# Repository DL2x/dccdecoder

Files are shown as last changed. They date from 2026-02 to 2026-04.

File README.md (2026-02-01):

This is my try at building my own dcc decoder. The code is funktional with a small PC817 Opto just hooked up to the track and an arduino, but Ive tried making a pcb for it (order is ongoing as of writing this).

There is currently no code for the PCB, as I dont yet have one of them here and cant test on it.

The PCB has support for 3 individual inputs (e.g. left rail, right rail and ac contact or overhead wire), with all of them providing power.

It does not support anything other than standard dcc, this includes no support for any analog system.

There are jumpers for connecting an AC motor: desolder both of then, then hook the 2 wires of the coil to the left and right ports and the neutral wire to the middle one. For DC motors just use the outer ones.

Feel free to contribute to this project!

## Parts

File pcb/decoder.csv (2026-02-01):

ID | Bezeichner | Footprint | Stückzahl | Bezeichnung | Anbieter und Referenz
1 | Q6,Q5,Q8,Q15,Q12,Q10 | SOT-23 | 6 | BC547
2 | R19,R8,R7,R16,R24,R14,R5,R28 | C_0201_0603Metric | 8 | 100
3 | D3,D5,D4,D15,D1,D2,D6 | D_SMA | 7 | SS34
4 | R27,R25,R15,R2,R21,R23,R29,R6,R18,R17,R4,R11 | C_0201_0603Metric | 12 | 100k
5 | R3 | C_0201_0603Metric | 1 | 10k
6 | R9,R20,R10,R13,R22,R26,R12,R30 | C_0201_0603Metric | 8 | 2k
7 | D9,D14,D10,D11,D12,D13 | D_SOD-523 | 6 | 15V
8 | C2,C4,C5 | C_0201_0603Metric | 3 | 100nF
9 | Q3,Q13,Q7,Q2,Q11,Q9 | TO-252-3_TabPin2 | 6 | FQP27P06
10 | JP3,JP2 | SolderJumper-2_P1.3mm_Bridged_Pad1.0x1.5mm | 2 | Jumper_2_Bridged
11 | Q1,Q4 | SOT-23 | 2 | IRLZ44N
12 | U1 | SOT-223-3_TabPin2 | 1 | LM7805_TO220
13 | U3 | SOIC-8_3.9x4.9mm_P1.27mm | 1 | 6N137
14 | R1 | C_0201_0603Metric | 1 | 1,3k
15 | JP1 | SolderJumper-2_P1.3mm_Open_Pad1.0x1.5mm | 1 | Jumper_2_Open
16 | D8 | D_SMA | 1 | D_TVS

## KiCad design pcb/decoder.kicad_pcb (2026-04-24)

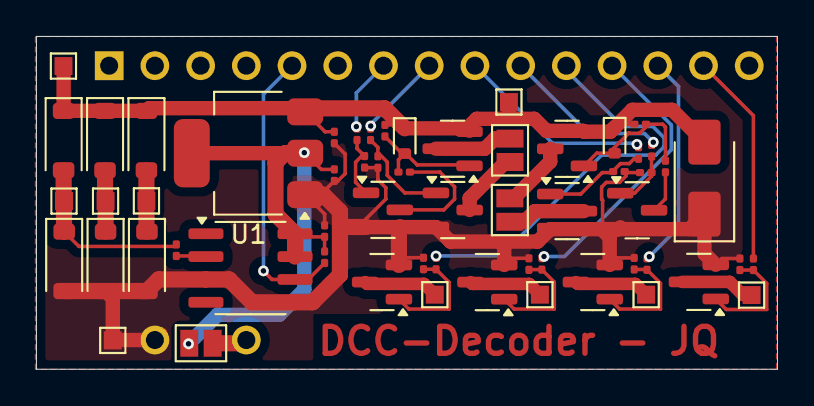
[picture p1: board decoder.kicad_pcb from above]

Board: 2 copper layers, 41.2 x 18.5 mm, 60 parts (1 on the bottom side), 37 nets.

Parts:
A1: Arduino_Nano_v3.x; Arduino_Nano
C2, C4, C5: 100nF; C_0201_0603Metric
D1, D2, D3, D4, D5, D15: MBR120VLSFT1G; D_SOD-123
D8: SMAJ24CA; D_SMA
D11, D12: BZT585B15T-7; D_SOD-523
J1, J2, J3, J4, J5, J6, J7, J9, J11, J12: Conn_01x01_Socket; TestPoint_Pad_1.0x1.0mm
JP1, JP2, JP4: Jumper_2_Open; SolderJumper-2_P1.3mm_Open_Pad1.0x1.5mm
Q1, Q4, Q7, Q8, Q10, Q14: FDN5630; SOT-23
Q2, Q3: NTR4171P; SOT-23
Q5, Q6: BC817; SOT-23
R1: 1,3k; C_0201_0603Metric
R2, R4, R6, R11, R15, R17, R23, R31: 100k; C_0201_0603Metric
R3: 10k; C_0201_0603Metric
R5, R7, R8, R14, R16, R18, R24, R32: 100; C_0201_0603Metric
R9, R10, R12, R13: 2k; C_0201_0603Metric
U1: AMS1117; SOT-223-3_TabPin2
U3: 6N137; SOIC-8_3.9x4.9mm_P1.27mm

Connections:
/5V: C2.1, C4.2, JP1.2 (B), R3.1, U1.2 (VO), U3.7 (EN), U3.8 (VCC)
/GND: A1.29 (GND), C2.2, C4.1, C5.1, D3.2 (A), D4.2 (A), D5.2 (A), D8.1 (A1), J11.1, Q1.2 (S), Q4.2 (S), Q5.2 (E), Q6.2 (E), Q7.2 (S), Q8.2 (S), Q10.2 (S), Q14.2 (S), R2.1, R6.1, R10.2, R13.2, R15.1, R17.1, R23.1, R31.1, U1.1 (ADJ), U3.3 (C), U3.5 (GND)
/Motor_A: JP4.1 (A), Q1.3 (D)
/Motor_A1: JP4.2 (B), Q2.3 (D)
/Motor_B: JP2.2 (B), Q4.3 (D)
/Motor_B1: JP2.1 (A), Q3.3 (D)
/VM: C5.2, D1.1 (K), D2.1 (K), D8.2 (A2), D11.1 (K), D12.1 (K), D15.1 (K), J9.1, J12.1, Q2.2 (S), Q3.2 (S), R4.1, R11.2, U1.3 (VI)
unnamed: A1.27 (+5V), JP1.1 (A)
unnamed: A1.5 (D2), R3.2, U3.6 (VO)
unnamed: A1.7 (D4), R12.1
unnamed: A1.8 (D5), R14.2
unnamed: A1.9 (D6), R5.2
unnamed: A1.10 (D7), R9.1
unnamed: A1.11 (D8), R32.2
unnamed: A1.12 (D9), R24.2
unnamed: A1.13 (D10), R18.2
unnamed: A1.14 (D11), R16.2
unnamed: D1.2 (A), D4.1 (K), J5.1
unnamed: D2.2 (A), D5.1 (K), J4.1
unnamed: D11.2 (A), Q3.1 (G), R4.2, R8.2
unnamed: D12.2 (A), Q2.1 (G), R7.2, R11.1
unnamed: D3.1 (K), D15.2 (A), J6.1, R1.2
unnamed: J1.1, Q8.3 (D)
unnamed: J2.1, Q7.3 (D)
unnamed: J3.1, Q10.3 (D)
unnamed: J7.1, Q14.3 (D)
unnamed: Q1.1 (G), R2.2, R5.1
unnamed: Q4.1 (G), R6.2, R14.1
unnamed: Q5.1 (B), R9.2, R13.1
unnamed: Q5.3 (C), R7.1
unnamed: Q6.1 (B), R10.1, R12.2
unnamed: Q6.3 (C), R8.1
unnamed: Q7.1 (G), R15.2, R16.1
unnamed: Q8.1 (G), R17.2, R18.1
unnamed: Q10.1 (G), R23.2, R24.1
unnamed: Q14.1 (G), R31.2, R32.1
unnamed: R1.1, U3.2 (A)

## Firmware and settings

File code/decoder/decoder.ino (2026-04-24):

#include <Arduino.h>

const byte dccPin = 2;

// ============================================================
// Ziel-Datentyp
// ============================================================

struct lokdada {
  bool richtung;         // true = vorwärts
  int geschwindigkeit;   // 0..127 normiert
  int funktionen[29];    // F0..F28, jeweils 0 oder 1
};

lokdada lokData;

// optional: zum Erkennen von Änderungen
lokdada prevLokData;

// Adressfilter
volatile int TARGET_ADDR = -1;   // -1 = alle, sonst kurze/lange Adresse

// nur für Diagnose
int currentDecodedAddr = -1;
bool currentDecodedIsLong = false;

// ============================================================
// DCC Rohdecoder (funktionierende Basis)
// ============================================================

volatile unsigned long lastEdge = 0;
volatile int pendingHalf = -1;      // -1 = none, 0 = long, 1 = short

volatile byte packet[8];
volatile byte packetLen = 0;
volatile byte curByte = 0;
volatile byte bitCount = 0;
volatile byte preambleCount = 0;
volatile bool inPacket = false;
volatile bool packetReady = false;

void resetDecoder() {
  pendingHalf = -1;
  packetLen = 0;
  curByte = 0;
  bitCount = 0;
  preambleCount = 0;
  inPacket = false;
}

void finishPacket() {
  packetReady = true;
  inPacket = false;
  curByte = 0;
  bitCount = 0;
  preambleCount = 1; // End-1 kann schon Teil der nächsten Präambel sein
}

void pushBit(byte b) {
  if (!inPacket) {
    if (b == 1) {
      preambleCount++;
    } else {
      if (preambleCount >= 10) {
        inPacket = true;
        packetLen = 0;
        curByte = 0;
        bitCount = 0;
      }
      preambleCount = 0;
    }
    return;
  }

  if (bitCount < 8) {
    curByte = (curByte << 1) | b;
    bitCount++;
    return;
  }

  // 9. Bit = Separator / Endbit
  if (packetLen < sizeof(packet)) {
    packet[packetLen++] = curByte;
  } else {
    resetDecoder();
    return;
  }

  curByte = 0;
  bitCount = 0;

  if (b == 1) {
    finishPacket();
  }
}

void dccISR() {
  unsigned long now = micros();
  unsigned long dt = now - lastEdge;
  lastEdge = now;

  int halfType = -1;

  // An deine Messung angepasst
  if (dt >= 44 && dt <= 68) {
    halfType = 1;   // kurze Halbwelle = DCC "1"
  } else if (dt >= 90 && dt <= 700) {
    halfType = 0;   // lange Halbwelle = DCC "0"
  } else {
    pendingHalf = -1;
    return;
  }

  if (pendingHalf == -1) {
    pendingHalf = halfType;
    return;
  }

  if (pendingHalf == halfType) {
    pushBit((byte)halfType);
  }

  pendingHalf = -1;
}

// ============================================================
// Hilfsfunktionen
// ============================================================

void resetLokData(lokdada &d) {
  d.richtung = true;
  d.geschwindigkeit = 0;
  for (int i = 0; i < 29; i++) d.funktionen[i] = 0;
}

void copyLokData(const lokdada &src, lokdada &dst) {
  dst.richtung = src.richtung;
  dst.geschwindigkeit = src.geschwindigkeit;
  for (int i = 0; i < 29; i++) dst.funktionen[i] = src.funktionen[i];
}

bool lokDataEquals(const lokdada &a, const lokdada &b) {
  if (a.richtung != b.richtung) return false;
  if (a.geschwindigkeit != b.geschwindigkeit) return false;
  for (int i = 0; i < 29; i++) {
    if (a.funktionen[i] != b.funktionen[i]) return false;
  }
  return true;
}

// Normierung auf 0..127
int normalizeSpeed(int rawStep, int rawMax) {
  if (rawStep <= 0) return 0;
  if (rawMax <= 0) return 0;

  long num = (long)(rawStep - 1) * 126L;
  long den = (long)(rawMax - 1);
  long scaled = 1L + (num + den / 2) / den;   // gerundet

  if (scaled < 1) scaled = 1;
  if (scaled > 127) scaled = 127;

  return (int)scaled;
}

bool packetXorOk(const byte* local, byte len) {
  if (len < 3) return false;
  byte x = 0;
  for (byte i = 0; i < len - 1; i++) x ^= local[i];
  return x == local[len - 1];
}

bool decodeLocoAddress(const byte* local, byte len, int& adr, bool& isLong, byte& instrIndex) {
  adr = -1;
  isLong = false;
  instrIndex = 1;

  if (len < 3) return false;

  // Idle ignorieren
  if (local[0] == 0xFF && local[1] == 0x00 && local[len - 1] == 0xFF) return false;

  // kurze Adresse: 0xxxxxxx
  if ((local[0] & 0x80) == 0) {
    adr = local[0];
    if (adr == 0 || adr == 0xFF) return false;
    isLong = false;
    instrIndex = 1;
    return true;
  }

  // lange Adresse: 11aaaaaa aaaaaaaa
  if ((local[0] & 0xC0) == 0xC0 && len >= 4) {
    adr = ((int)(local[0] & 0x3F) << 8) | local[1];
    isLong = true;
    instrIndex = 2;
    return true;
  }

  return false;
}

void printLokData(const lokdada &d) {
  Serial.print("richtung: ");
  Serial.println(d.richtung ? "true" : "false");

  Serial.print("geschwindigkeit: ");
  Serial.println(d.geschwindigkeit);

  Serial.print("funktionen: [");
  for (int i = 0; i < 29; i++) {
    if (i) Serial.print(", ");
    Serial.print(d.funktionen[i]);
  }
  Serial.println("]");
}

// ============================================================
// Decoder in lokdada
// ============================================================

void decodeFunctions_F0_F4(byte instr, lokdada &d) {
  d.funktionen[0] = bitRead(instr, 4) ? 1 : 0;   // F0

  for (int i = 0; i < 4; i++) {
    d.funktionen[1 + i] = bitRead(instr, i) ? 1 : 0;   // F1..F4
  }
}

void decodeFunctions_F5_F8(byte instr, lokdada &d) {
  for (int i = 0; i < 4; i++) {
    d.funktionen[5 + i] = bitRead(instr, i) ? 1 : 0;
  }
}

void decodeFunctions_F9_F12(byte instr, lokdada &d) {
  for (int i = 0; i < 4; i++) {
    d.funktionen[9 + i] = bitRead(instr, i) ? 1 : 0;
  }
}

void decodeFunctions_F13_F20(byte value, lokdada &d) {
  for (int i = 0; i < 8; i++) {
    d.funktionen[13 + i] = bitRead(value, i) ? 1 : 0;
  }
}

void decodeFunctions_F21_F28(byte value, lokdada &d) {
  for (int i = 0; i < 8; i++) {
    d.funktionen[21 + i] = bitRead(value, i) ? 1 : 0;
  }
}

void decodeSpeed14_28(byte instr, lokdada &d) {
  bool forward = bitRead(instr, 5);

  byte v = (instr & 0b00001111) << 1;
  bitWrite(v, 0, bitRead(instr, 4));   // zusätzliches Speed-Bit

  int step28;
  switch (v) {
    case 0:
    case 1:
    case 2:
    case 3:
      step28 = 0;  // Stop / E-Stop zusammengefasst
      break;
    default:
      step28 = (int)v - 3;   // 1..28
      break;
  }

  d.richtung = forward;
  d.geschwindigkeit = normalizeSpeed(step28, 28);
}

void decodeSpeed128(byte speedByte, lokdada &d) {
  bool forward = bitRead(speedByte, 7);
  byte v = speedByte & 0x7F;

  int step126;
  if (v == 0 || v == 1) step126 = 0;   // Stop / E-Stop zusammengefasst
  else step126 = (int)v - 1;           // 1..126

  d.richtung = forward;
  d.geschwindigkeit = normalizeSpeed(step126, 126);
}

void decodePacketToLokData(const byte* local, byte len, lokdada &d) {
  if (!packetXorOk(local, len)) return;

  int adr;
  bool isLong;
  byte instrIndex;

  if (!decodeLocoAddress(local, len, adr, isLong, instrIndex)) return;
  if (TARGET_ADDR >= 0 && adr != TARGET_ADDR) return;
  if (instrIndex >= len - 1) return;

  currentDecodedAddr = adr;
  currentDecodedIsLong = isLong;

  byte instr = local[instrIndex];

  // F0..F4 : 100xxxxx
  if ((instr & 0b11100000) == 0b10000000) {
    decodeFunctions_F0_F4(instr, d);
  }

  // F5..F8 : 1011xxxx
  if ((instr & 0b11110000) == 0b10110000) {
    decodeFunctions_F5_F8(instr, d);
  }

  // F9..F12 : 1010xxxx
  if ((instr & 0b11110000) == 0b10100000) {
    decodeFunctions_F9_F12(instr, d);
  }

  // 14/28 Fahrstufen : 01xxxxxx
  if ((instr & 0b11000000) == 0b01000000) {
    decodeSpeed14_28(instr, d);
  }

  // 128 Fahrstufen : 0x3F + Folgebyte
  if (instr == 0x3F && (instrIndex + 1) < (len - 1)) {
    decodeSpeed128(local[instrIndex + 1], d);
  }

  // Erweiterte Funktionen
  if (instr == 0xDE && (instrIndex + 1) < (len - 1)) {
    decodeFunctions_F13_F20(local[instrIndex + 1], d);
  }

  if (instr == 0xDF && (instrIndex + 1) < (len - 1)) {
    decodeFunctions_F21_F28(local[instrIndex + 1], d);
  }
}

// ============================================================
// Serial
// ============================================================

void handleSerial() {
  if (!Serial.available()) return;

  String s = Serial.readStringUntil('\n');
  s.trim();
  if (s.length() == 0) return;

  if (s.equalsIgnoreCase("ALL")) {
    TARGET_ADDR = -1;
    resetLokData(lokData);
    resetLokData(prevLokData);
    currentDecodedAddr = -1;
    currentDecodedIsLong = false;
    Serial.println("Filter: ALL");
    return;
  }

  if (s.charAt(0) == 'S' || s.charAt(0) == 's') {
    int adr = s.substring(1).toInt();
    if (adr >= 1 && adr <= 127) {
      TARGET_ADDR = adr;
      resetLokData(lokData);
      resetLokData(prevLokData);
      currentDecodedAddr = -1;
      currentDecodedIsLong = false;
      Serial.print("Filter kurze Adresse: ");
      Serial.println(TARGET_ADDR);
    } else {
      Serial.println("Kurzadresse muss 1..127 sein");
    }
    return;
  }

  if (s.charAt(0) == 'L' || s.charAt(0) == 'l') {
    int adr = s.substring(1).toInt();
    if (adr >= 128 && adr <= 10239) {
      TARGET_ADDR = adr;
      resetLokData(lokData);
      resetLokData(prevLokData);
      currentDecodedAddr = -1;
      currentDecodedIsLong = false;
      Serial.print("Filter lange Adresse: ");
      Serial.println(TARGET_ADDR);
    } else {
      Serial.println("Langadresse muss 128..10239 sein");
    }
    return;
  }

  if (s.equalsIgnoreCase("PRINT")) {
    Serial.print("adresse: ");
    Serial.println(currentDecodedAddr);
    Serial.print("adressmodus: ");
    Serial.println(currentDecodedIsLong ? "long" : "short");
    printLokData(lokData);
    return;
  }

  Serial.println("Kommandos: ALL, S<num>, L<num>, PRINT");
}

// ============================================================
// Setup / Loop
// ============================================================

void setup() {
  Serial.begin(115200);
  pinMode(dccPin, INPUT);
  attachInterrupt(digitalPinToInterrupt(dccPin), dccISR, CHANGE);

  resetDecoder();
  resetLokData(lokData);
  resetLokData(prevLokData);

  Serial.println("DCC Decoder mit lokdada gestartet");
  Serial.println("Kommandos: ALL, S<num>, L<num>, PRINT");
}

void loop() {
  handleSerial();

  if (packetReady) {
    noInterrupts();
    byte len = packetLen;
    byte local[8];
    for (byte i = 0; i < len; i++) local[i] = packet[i];
    packetReady = false;
    interrupts();

    decodePacketToLokData(local, len, lokData);

    // Nur für Diagnose: bei Änderung ausgeben
    if (!lokDataEquals(lokData, prevLokData)) {
      Serial.print("adresse: ");
      Serial.println(currentDecodedAddr);
      Serial.print("adressmodus: ");
      Serial.println(currentDecodedIsLong ? "long" : "short");
      printLokData(lokData);
      Serial.println();

      copyLokData(lokData, prevLokData);
    }
  }
}

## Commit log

2026-02-01 add code and pcb, update readme, add gitignore
    [decoder.csv, decoder.kicad_pcb, decoder.kicad_sch]
2026-02-05 make PCB smaller
    [decoder.kicad_pcb, decoder.kicad_sch]
2026-02-06 fix some pcb part numbers
    [decoder.kicad_pcb, decoder.kicad_sch]
2026-04-24 add tests
    [decoder.kicad_pcb, decoder.kicad_sch]
